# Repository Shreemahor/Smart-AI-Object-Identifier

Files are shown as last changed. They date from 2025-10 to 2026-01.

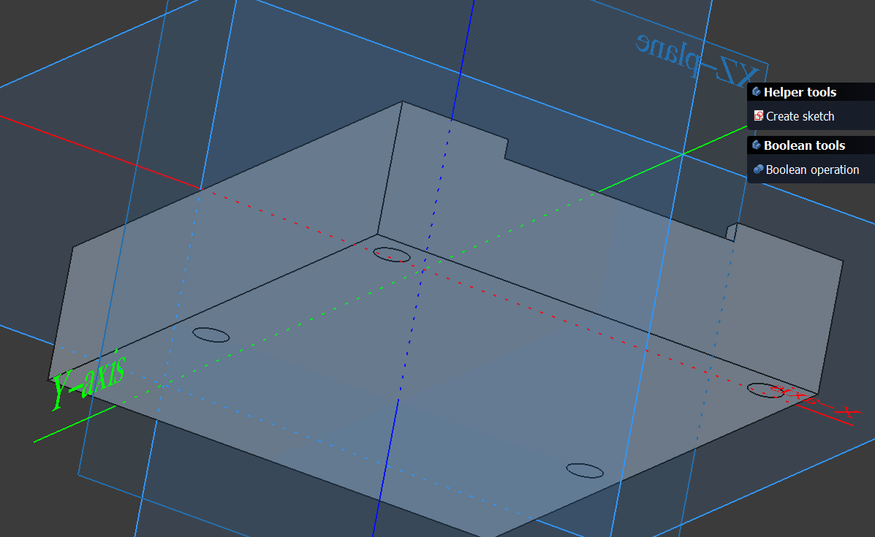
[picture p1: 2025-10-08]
Case Model/back.png

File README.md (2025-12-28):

# Smart AI Object Identifier 🤖
***A camera with a 3D printed case controlled by a raspberry pi, identifying what's in front of it and then displaying it on an LCD***



**Video of it in action:**

identifier
## What is it?

There is a raspberry pi 5 which runs object recognition, and this is connected to an arducam whose case I have 3D printed.
The raspberry pi 5 is also connected to an LCD display. When something is placed in front, the camera detects it, labels it, then that label is displayed 
on the LCD.

## Why?

The process of identifying something using a camera and then acting has many applications. One of these is a manufacturing line where this could be used to identify defects then stop to grab the 
defected peice. Other than that, designing the camera model was a great way for me to learn CAD. Most computer vision systems display what was identified on the computer, so this LCD instantaneously 
displaying it makes it feel more magical. 

## Structure

*Case model* has the files for the camera case, and the *Failed model* contains the old 3d model for the case, but did not work because its dimensions were not correct.
Assembly and Assembly-2 both have details on how I made it, the commands I ran, more problems I faced, and details of how I accomplised it.






identifier

identifier-render
On the render is says "pico" but it represents the Pi 5



Smart AI Object Identifier is a simple yet useful project that uses computer vision and a camera with a 3d printed case to identify objects then displays them on the lcd.

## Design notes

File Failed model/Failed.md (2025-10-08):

\# Challenges Faced

There were many issues with this old model.

&nbsp;	- It had mounting holes of 2.2mm diameter but then I decided upon 1.8

&nbsp;	- Its measurements were slightly off especially at the edges

&nbsp;	- There were unnecessary screw bosses

When I tried fixing these, many previous parts of my model crashed and I was unable to progress.

\# Fix

This is the transition between my second and third journal entry. I took measurements again and started fresh, taking the old model of inspiration.

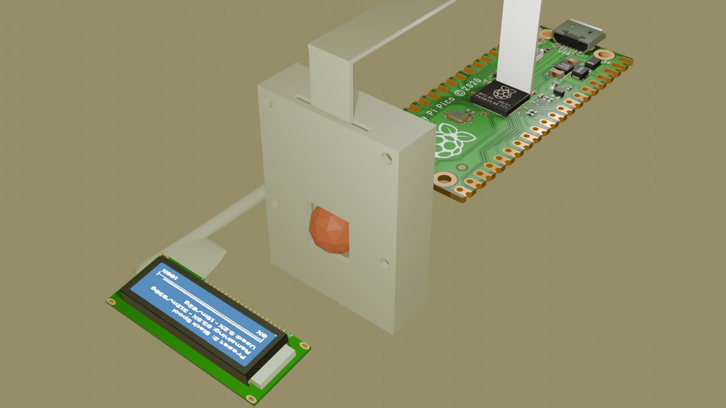
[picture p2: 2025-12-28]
identifier-render.png

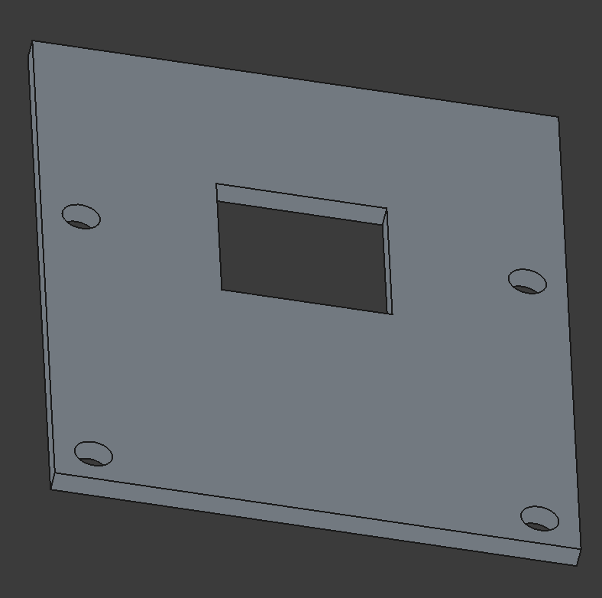
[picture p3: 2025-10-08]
Case Model/front.png

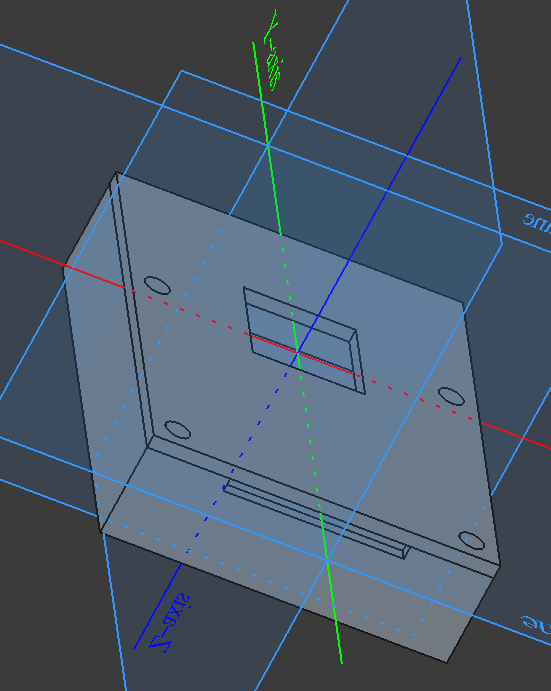
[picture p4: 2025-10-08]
Case Model/fullview.png

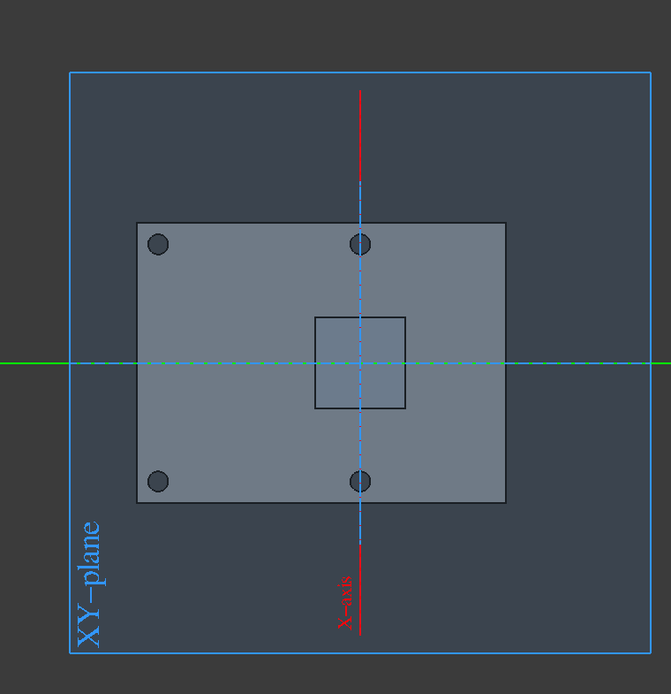
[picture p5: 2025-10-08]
Case Model/topview.png

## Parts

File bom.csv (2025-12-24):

Component | Price | Link | Quantity | Description
Raspberry Pi 5 | 169.95 | https://www.amazon.com/CanaKit-Raspberry-Starter-Kit-PRO/dp/B0CRSNCJ6Y | 1 | mini-computer
Arducam IMX519 | 24.99 | https://www.amazon.com/Arducam-IMX519-Autofocus-Raspberry-Compatible/dp/B0B3XBQM9Z | 1 | camera
LCD Display | 12.99 | https://www.amazon.com/Hosyond-Display-Module-Arduino-Raspberry/dp/B0BWTFN9WF | 1 | display
M2 screws | 9.99 | https://www.amazon.com/Fgruh-1200PCS-Assortment-Washers-Assorted/dp/B0FGV5K8BT | 1 | for case connection - but I actually used tape
Wires | 3.99 | https://www.amazon.com/California-JOS-Breadboard-Optional-Multicolored/dp/B0BRTJQGS6 | 1 | lcd connection
Screwdriver | 7.39 | https://www.amazon.com/Amazon-Brand-6-Multi-Bit-Screwdriver/dp/B09G7J1X2N | 1 | for adjusting lcd backlight

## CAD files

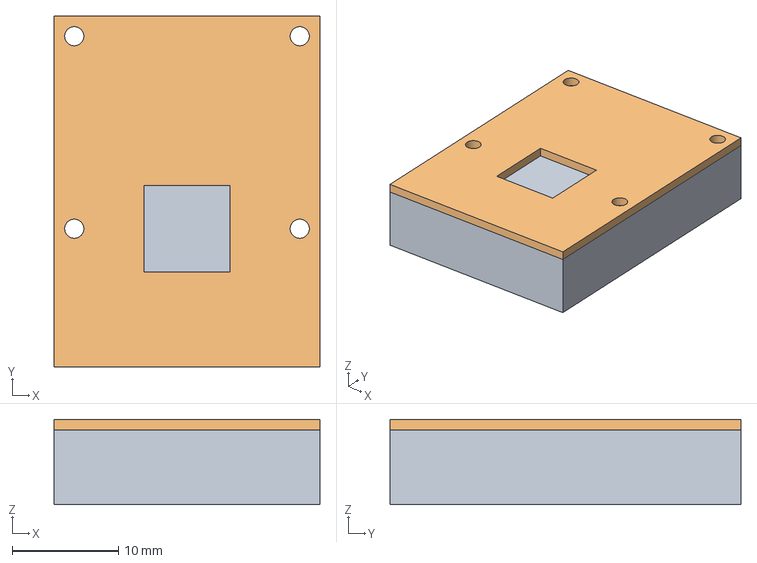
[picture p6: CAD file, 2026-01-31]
Case Model/Arducam.step
25.0 x 33.0 x 8.00 mm
Front

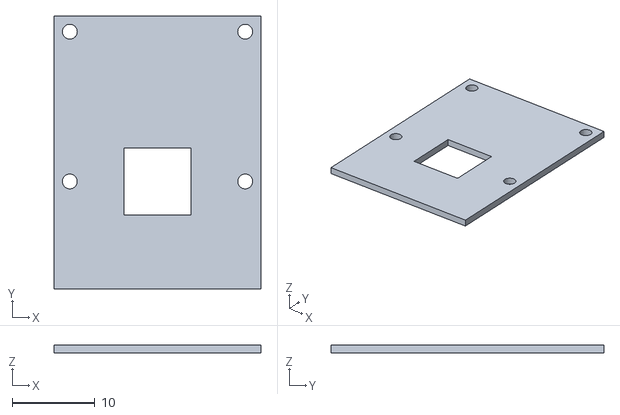
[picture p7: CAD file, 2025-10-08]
Case Model/Arducam-Front.obj
25.0 x 33.0 x 1.00

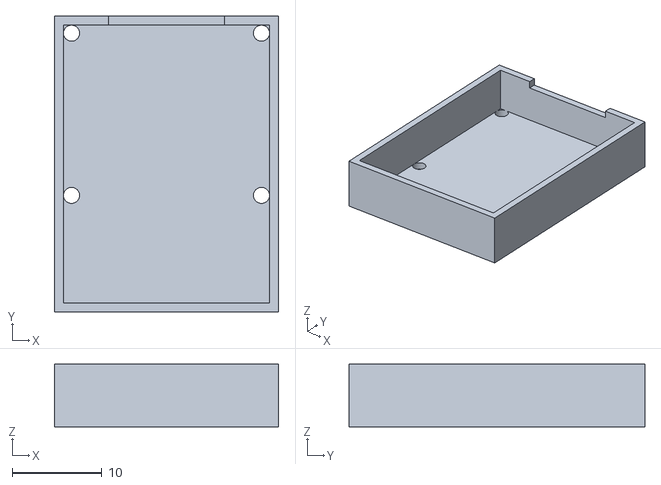
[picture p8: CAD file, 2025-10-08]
Case Model/Arducam-Body.obj
25.0 x 33.0 x 7.00

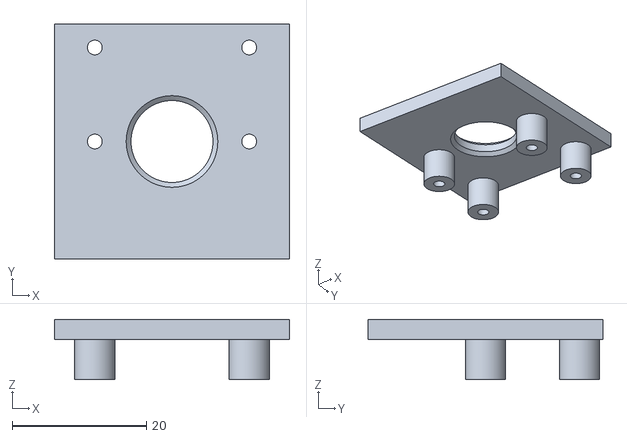
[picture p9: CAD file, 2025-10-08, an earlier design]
Failed model/OldArducam-Front.obj
35.0 x 35.0 x 9.00

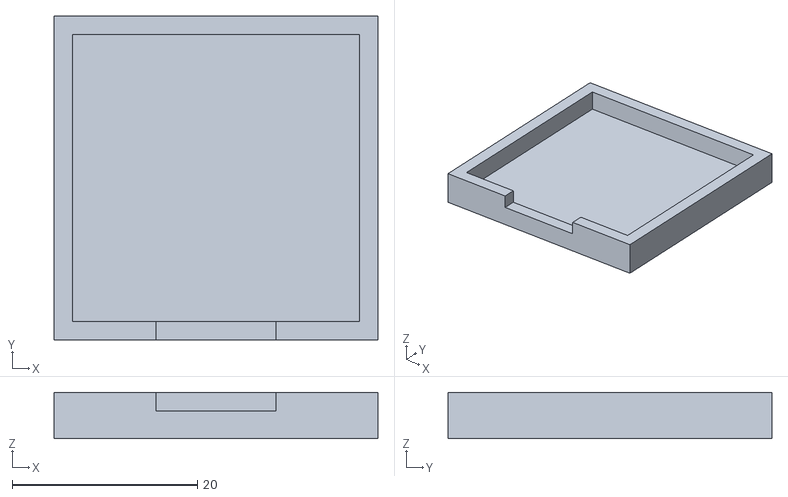
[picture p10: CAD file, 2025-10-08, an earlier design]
Failed model/OldArducam-Back.obj
35.0 x 35.0 x 5.00

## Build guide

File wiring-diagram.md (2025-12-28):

identifier

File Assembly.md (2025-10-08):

# Process for Assebling Case for Camera

## Parts

The parts are:
  1. Body - as in Arducam-Body.obj
  2. Front - as in Arducam-Front.obj

Both were made using FreeCAD.

## Significance

The front is the main front-facing side that has the slot for the camera lense and holes for the screws to go through.
The back is the other 5 sides and has a coin-like slot that is used to insert the ribbon cable.

## Procedure

### Before starting

Be sure to have connected your Arducam to the pi once and used libcamera commands to verify it works.

### Procedure

1. Place Front bottom-up flat on the floor
2. Insert your arducam so that the lenses goes inside the hole and the mounting holes align
3. Carefully put the ribbon cable through the thin coin-like ribbon cable hole at the bottom of Body
4. Place Front and the camera, now connected, on top of Body, making sure the mounting holes align
5. Put the M2 Screw through the mounting hole, repear for the other 3 screws
6. Twist the M2 Nut onto the back of the M2 Screw, repeat for the other 3 nuts
7. Align everything so that Front is facing towards you and ensure that the camera is firm
8. Attach the other end of the cable back onto the pi

## Test

Confirm lib-camera commands work again

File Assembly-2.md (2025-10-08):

# Smart AI Object Identifier

## Overview

This project aims to identify the object in the screenshot taken by a camera using AI and computer vision

## Connecting

There are two main parts:
  - Raspberry Pi 5
  - Arducam

First, unlock the ribbon cable connector on the arducam and pi by lifting the metal hinge on each one. Now choose one end and put it blue face facing the lense of the arducam. Next, put the other end of the cable into the raspberry pi's connector, shiny face facing the pi's
usb ports. Now make sure both ends have fit in snugly and close the hinge by gently tapping it down.

## 3D Case

The Arducam is quite fragile so it needs a case to stand up straight and be suitable for taking images safer and at a better angle.
More details at Assembly.md.

## Using

Once you open the raspberry pi 5 there are some commands to run to ensure the camera is funcioning. Firstly, run **sudo raspi-config** and navigate to settings to enable the camera. Now in the *libcamera library*, a libary used for interacting with cameras there are some basic
commands to run:
  1. libcamera-hello - Displayes a simple preview
  2. libcamera-hello -t 8000 - Display a simple preview for 8000ms or 8s
  3. libcamera-still -o example_image.jpg - Captures an image
  4. libcamera-vid -o example_video.mp4 -t 9000 - Captures a video with a duratio of 9s

## Computer Vison

Need to open Thonny the lightweight python editor. Need to use machine learning libraries like OpenCV and image processing libraries like MatPlotLib but I dont know the exact code because I have not set up hardware yet.

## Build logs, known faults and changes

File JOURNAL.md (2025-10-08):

<!--
  ===================    !!READ THIS NOTICE!!   ====================
  DO NOT edit this file manually. Your changes WILL BE OVERWRITTEN!
  This journal is auto generated and updated by Hack Club Blueprint.
  To edit this file, please edit your journal entries on Blueprint.
  ==================================================================
-->

This is my journal of the design and building process of **Smart AI Object Identifier 🤖**.  
You can view this journal in more detail on **Hack Club Blueprint** [here](https://blueprint.hackclub.com/projects/290).

## 10/7/2025 4 PM - Firstly, started making CAD  



# Making a CAD for the Camera first

## Research

I know I need a Raspberry Pi, Picamera, and some software. My biggest problem is that my Picamera is in a cardboard box and needs to be upgraded, so I plan to 3d print a new case for it.

## CAD

Right now it is in a loose cardboard case and that must be fixed. I am going to be using ***FreeCAD*** for making CAD designs.

I have just started making a hole for the front side of the camera, but it seems that its structure is *far more complex* than what I first thought. I am going to upskill in FreeCAD and finish the CAD for the camera.  

## 10/7/2025 8 PM - Finished Camera's Case CAD  


# Progress

## Learning

I needed to learn lots of new parts of *FreeCAD* like:
	- Chamfers
	- fillets
	- thick solids
Many function created hassles by giving errors. I needed to go back and read how to use them and correct these errors.

## Parts of Camera

### Front

Has chamfered hole for camera lens and holes for *screws* and *bosses* (but these are not finalized). Front facing part of camera, measured to accuracy.

### Main body

Has a coin-like slot for the camera cable. Very box-like because its a thick solid.

### Future

***Securing Mechanism*** must be fixed. Its unclear if the screws, bolts, and bosses will work with the model.  

## 10/8/2025 12 AM - Finalized Design & Fastening  



# Finalized Design

## Issue

There were screw bosses that I put on and didn't know much about. Now I know that it is supposed to help screws but I put it on wrong. I also put the radius of the holes wrong because I didn't know what I was going to do. I spent a long time trying different things to fix it but nothing worked

## Research

I measured my camera more and compared options. I measured things like the radius of the lense, border, and center more carefully. I evaluated which fastening method to use I considered connectors, coppers, and self-tapping screws, but I decided on ***M2*10 Philips Screw*** and ***M2 Nuts*** on the ends to secure.


## Fix

I needed to change the size of holes (except the ribbon cable channel). I removed the bosses and realized that this is enough.  

## 10/8/2025 4 AM - Finished final descriptions, .md .csv  


# .md

I made many md files that presented an overview of the project and mistakes.
README.md starts with some installation and a summary of the project.
Assembly.md is all about assembly.
Failed.md is a summary of the errors in the old model.

# .csv

This took some research to understand what part numbers are and what a .csv file really is. I spent some time looking at my materials deeper.

# Final touches on model

I reflected on the old model from journal entry 1 and 2. I ensure the new model had no conflicting sides and was fully constrained. I also finally inspected it from all sides and took pictures.

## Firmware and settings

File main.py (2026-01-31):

import cv2
import numpy as np
from picamera2 import Picamera2
import time

from lcd_simple_test import lcd

try:
    from tensorflow.lite.python.interpreter import Interpreter
except ImportError:
    print("TensorFlow not found")
    exit(1)


class ObjectDetector:
    def __init__(self, model_path='detect.tflite', labels_path='labelmap.txt'):
        """
        Initialize the object detector
        """
        self.model_path = model_path
        self.labels_path = labels_path
        
        # Load labels
        self.labels = self.load_labels()
        
        # Initialize TFLite interpreter
        self.interpreter = Interpreter(model_path=self.model_path)
        self.interpreter.allocate_tensors()
        
        # Get input and output details
        self.input_details = self.interpreter.get_input_details()
        self.output_details = self.interpreter.get_output_details()
        
        # Get input shape
        self.input_shape = self.input_details[0]['shape']
        self.height = self.input_shape[1]
        self.width = self.input_shape[2]
        
        print(f"Model loaded. Input shape: {self.input_shape}")
        
    def load_labels(self):
        """Load labels from file"""
        try:
            with open(self.labels_path, 'r') as f:
                labels = [line.strip() for line in f.readlines()]
            # Remove first label if it's '???'
            if labels[0] == '???':
                labels.pop(0)
            return labels
        except FileNotFoundError:
            print(f"Labels file not found: {self.labels_path}")
            print("Using default COCO labels...")
            # Return some common COCO labels
            return ['person', 'bicycle', 'car', 'motorcycle', 'airplane', 'bus', 
                   'train', 'truck', 'boat', 'traffic light', 'fire hydrant', 
                   'stop sign', 'parking meter', 'bench', 'bird', 'cat', 'dog']
    
    def detect_objects(self, frame, threshold=0.5):
        """
        Detect objects in a frame
        Returns:
            List of detections with (label, confidence, bbox)
        """
        # Preprocess image
        img = cv2.cvtColor(frame, cv2.COLOR_BGR2RGB)
        img_resized = cv2.resize(img, (self.width, self.height))
        input_data = np.expand_dims(img_resized, axis=0)
        
        # Normalize if needed (depends on model)
        if self.input_details[0]['dtype'] == np.float32:
            input_data = (np.float32(input_data) - 127.5) / 127.5
        
        # Run inference
        self.interpreter.set_tensor(self.input_details[0]['index'], input_data)
        self.interpreter.invoke()
        
        # Get results
        boxes = self.interpreter.get_tensor(self.output_details[0]['index'])[0]
        classes = self.interpreter.get_tensor(self.output_details[1]['index'])[0]
        scores = self.interpreter.get_tensor(self.output_details[2]['index'])[0]
        
        detections = []
        for i in range(len(scores)):
            if scores[i] > threshold:
                class_id = int(classes[i])
                label = self.labels[class_id] if class_id < len(self.labels) else f"Class {class_id}"
                confidence = scores[i]
                bbox = boxes[i]
                detections.append((label, confidence, bbox))
        
        return detections


def main():
    """Main function to run object detection"""
    
    print("Initializing camera...")
    
    # Initialize Picamera2 for Arducam
    picam2 = Picamera2()
    
    # Configure camera
    config = picam2.create_preview_configuration(
        main={"size": (640, 480), "format": "RGB888"}
    )
    picam2.configure(config)
    picam2.start()
    
    print("Camera started. Waiting for it to warm up...")
    time.sleep(2)
    
    # Initialize object detector
    print("Loading object detection model...")
    try:
        detector = ObjectDetector()
    except FileNotFoundError:
        print("\nERROR: Model files not found!")
        print("Please download the TensorFlow Lite model that is used for the recognition:")
        print("1. Download it from: https://storage.googleapis.com/download.tensorflow.org/models/tflite/coco_ssd_mobilenet_v1_1.0_quant_2018_06_29.zip")
        print("2. Extract and place 'detect.tflite' and 'labelmap.txt' in this directory")
        picam2.stop()
        return
    
    print("\nStarting object detection...")
    print("Press Ctrl+C to exit\n")
    
    try:
        frame_count = 0
        while True:
            # Capture frame
            frame = picam2.capture_array()
            
            # Flip frame vertically
            frame = cv2.flip(frame, 0)
            
            # Convert RGB to BGR for OpenCV
            frame_bgr = cv2.cvtColor(frame, cv2.COLOR_RGB2BGR)
            
            # Detect objects
            detections = detector.detect_objects(frame_bgr, threshold=0.5)
            
            # Print detections
            if detections and frame_count % 10 == 0:  # Print every 10 frames
                print(f"\n--- Frame {frame_count} ---")
                for label, confidence, bbox in detections:
                    print(f"  {label}: {confidence*100:.1f}%")
                    lcd.clear()
                    lcd.write_string(label)
            
            # Draw boxes on frame
            h, w = frame_bgr.shape[:2]
            for label, confidence, bbox in detections:
                ymin, xmin, ymax, xmax = bbox
                xmin = int(xmin * w)
                xmax = int(xmax * w)
                ymin = int(ymin * h)
                ymax = int(ymax * h)
                
                # Draw rectangle
                cv2.rectangle(frame_bgr, (xmin, ymin), (xmax, ymax), (0, 255, 0), 2)
                
                # Draw label
                label_text = f"{label}: {confidence*100:.0f}%"
                cv2.putText(frame_bgr, label_text, (xmin, ymin - 10),
                           cv2.FONT_HERSHEY_SIMPLEX, 0.5, (0, 255, 0), 2)
            
            # Display frame (optional - comment out if running headless)
            try:
                cv2.imshow('Object Detection', frame_bgr)
                if cv2.waitKey(1) & 0xFF == ord('q'):
                    break
            except:
                # If display fails , just continue
                pass
            
            frame_count += 1
            time.sleep(0.1)  # Small delay to reduce CPU usage
            
    except KeyboardInterrupt:
        print("\n\nStopping...")
    finally:
        picam2.stop()
        cv2.destroyAllWindows()
        print("bye!")


if __name__ == "__main__":
    main()

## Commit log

2025-10-08 Add BOM.csv
    has all the materials
    [BOM.csv]
2025-10-08 Update BOM.csv with new components and quantities
    [BOM.csv]
2025-10-08 Add assembly instructions for camera case
    Document the assembly process for the camera case, including parts, significance, and step-by-step procedure.
2025-10-08 Details for the 3D Model
    [Arducam-Body.obj, Arducam-Front.obj]
2025-10-08 Old Model - No longer in use
    [OldArducam-Back.obj, OldArducam-Front.obj]
2025-12-24 Add documentation for Smart AI Object Identifier project
    Added documentation for the Smart AI Object Identifier project, including setup instructions for Raspberry Pi and Arducam, usage commands, and an overview of required software.
2025-12-24 Revise bom.csv to include detailed component info
    Updated bill of materials with prices, links, and descriptions.
    [bom.csv]
2025-12-27 Added wiring diagram
    Added an additional image to the README for better visualization.
2025-12-27 Adding Wiring Diagram
2025-12-28 Add wiring diagram image to documentation
2026-01-31 Implement object detection using TensorFlow Lite
    This script implements an object detection system using TensorFlow Lite and a camera interface. It captures frames, processes them for object detection, and displays results on lcd
